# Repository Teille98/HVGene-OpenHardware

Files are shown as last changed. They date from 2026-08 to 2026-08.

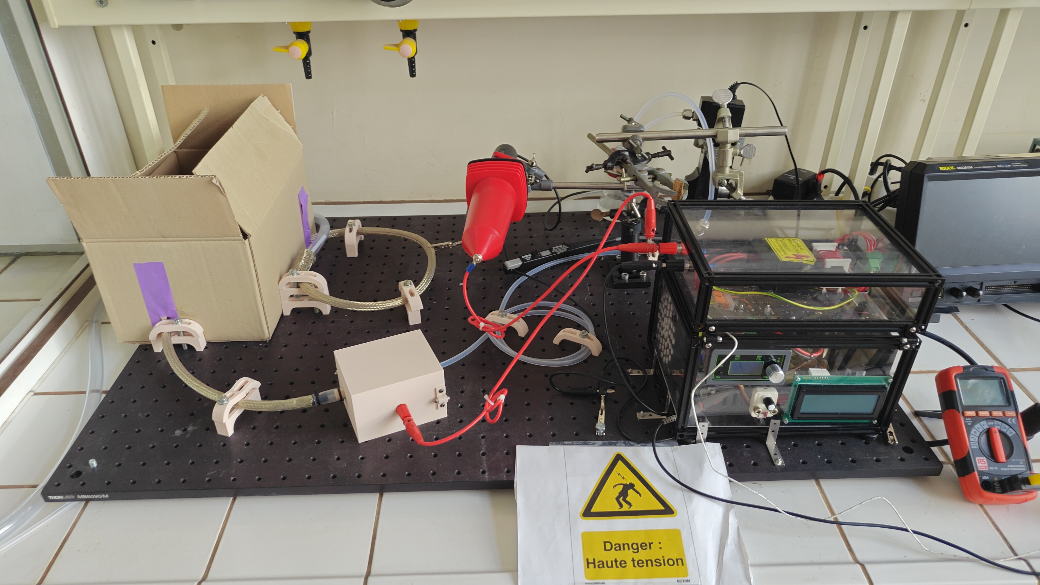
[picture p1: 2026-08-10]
docs/Figures/Setup_Photos/setup_1.jpg

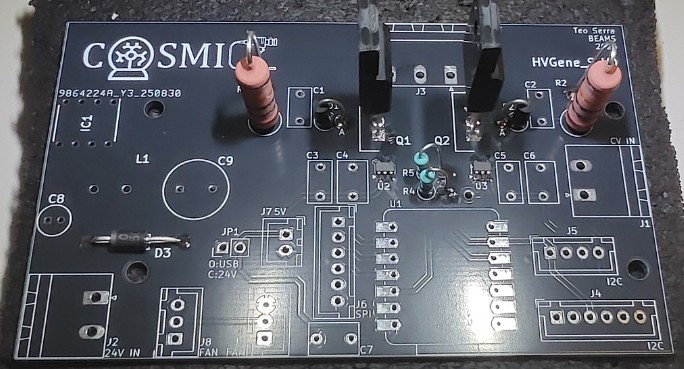
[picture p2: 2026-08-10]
docs/Figures/Build_Steps/PCB_step3&4.jpg

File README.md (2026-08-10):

# HVGene — Open-Source High-Voltage Power Supply for Cold Atmospheric Plasma

Open-source, digitally controlled high-voltage AC power supply for cold atmospheric
plasma (CAP) research, developed with a specific focus on flexible-endoscope
decontamination applications. The platform delivers either continuous sinusoidal
high-voltage excitation or pulsed AC trains, with explicit user control over input
voltage, operating frequency, duty cycle, timing, and operating mode.

This repository accompanies the following HardwareX article:

> *Open-Source High Voltage Power Supply for Cold Atmospheric Plasma Production*,
> HardwareX (2026). DOI: _to be added once assigned_.

If you use this hardware, firmware, or documentation, please cite the article above.

## Repository structure

This project mixes three kinds of content, each released under the license most
appropriate for that kind of content — see the `LICENSE` file inside each folder
for the exact terms.

```
HVGene_OpenHardware/
├── hardware/          Electronics and mechanical design files
│   ├── LICENSE        CERN-OHL-P-2.0 (permissive open hardware licence, unmodified)
│   ├── NOTICE          Copyright notice (kept separate — the licence text itself
│   │                   must not be modified, per its own Preamble)
│   ├── KiCAD/          PCB schematic and layout (push-pull inverter board)
│   ├── CAD-Fusion360/  3D mechanical design (enclosure, mounting)
│   ├── Cutting/        Laser-cutting SVG files (LV/HV plates)
│   └── BOM.xlsx        Bill of materials
├── firmware/           RP2040 / MicroPython control firmware
│   ├── LICENSE          MIT
│   ├── main.py, lib/    Firmware source
│   └── tests/           Bench validation scripts (I2C, PIO, timing)
├── docs/                Build photos, diagrams, and other documentation media
│   ├── LICENSE           CC BY-SA 4.0
│   └── Figures/          All figures used in the article, plus device/setup/plasma
│                         photos, CAD renders, build-step and scope-capture images
└── zip/                 Pre-packaged .zip archives of the folders above, matching
                          the Design Files table in the HardwareX article
```

## Versioning

The version tagged and archived alongside the HardwareX article submission is the
exact hardware/firmware state described and validated in that article. This
repository may continue to evolve after that point (bug fixes, improvements,
community contributions); the archived release is the one to use for reproducing
the results reported in the article.

## Safety

This hardware generates high voltages (up to several tens of kV) and involves
mains-connected power electronics. Building and operating it requires
appropriate electrical safety training. See the "Safety Concerns" and
"Operation instructions" sections of the article before use.

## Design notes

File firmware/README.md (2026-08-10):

# HVGene

## Quick Description

HVGene is an RP2040-based high-voltage signal generator (MicroPython) with an I2C LCD and rotary encoder user interface.

The firmware provides two modes:
- SQUARE: continuous square signal
- PULSE: ON/OFF gating of the square signal with adjustable pulse frequency and duty cycle

## Target Hardware

- RP2040 (Raspberry Pi Pico / XIAO RP2040)
- M5Stack U135 encoder (I2C 0x40)
- LCD 20x4 NHD-0420D3Z (I2C 0x28)

Used pins:
- GPIO0: MOSFET A gate (PIO SM0, push-pull)
- GPIO1: MOSFET B gate (PIO SM0, complementary — same SM as GPIO0)
- GPIO6: I2C SDA
- GPIO7: I2C SCL

> **Note**: there is no dedicated "pulse gate" pin. PULSE mode gating is
> achieved by overriding the GPIO pad OUTOVER registers (RP2040 CTRL),
> which forces both GPIO0/GPIO1 LOW without stopping the PIO SM.

## Quick Start

1. Flash MicroPython onto the RP2040.
2. Copy main.py and the lib/ folder to the board.
3. Connect the RP2040 to the custom PCB.
4. Reboot the board.

## Project Structure

```
HVGene_Simple/
|-- main.py
|-- README.md
|-- lib/
|   |-- config.py
|   |-- generator.py
|   |-- hardware.py
|   |-- logger.py
|   |-- pio_programs.py
|   |-- storage.py
|   `-- README.md
`-- tests/
    |-- README.md
    |-- test_i2c_devices.py
    |-- test_lcd_output.py
    |-- test_encoder.py
    |-- test_gpio_output.py
    |-- test_pio_simple.py
    |-- test_pulse_timing.py
    `-- test_duty_cycle.py
```

## Main File Roles

- `main.py`: firmware entry point.
- `lib/config.py`: configuration constants (GPIO, frequencies, UI limits).
- `lib/pio_programs.py`: PIO program for push-pull drive.
- `lib/hardware.py`: I2C drivers (encoder + LCD).
- `lib/generator.py`: application logic and UI state machine.
- `lib/logger.py`: logging.
- `lib/storage.py`: settings save/load.
- `tests/`: hardware and timing validation scripts.

## Tests

The recommended procedure and test descriptions are available in [tests/README.md](tests/README.md).

Recommended order:
1. `test_i2c_devices.py`
2. `test_lcd_output.py`
3. `test_encoder.py`
4. `test_gpio_output.py`
5. `test_pio_simple.py`
6. `test_pulse_timing.py`
7. `test_duty_cycle.py`

## License

MIT — see [LICENSE](LICENSE).

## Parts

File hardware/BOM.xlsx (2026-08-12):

Category | Designator | Part | Value | Component / Ref. | Qty | Unit cost | Total cost | Supplier | Source of materials | Notes
PCB | U1 | MicroC |  | Seeed Studio XIAO RP2040 | 1 | 5.24 € | 5.24 € | RS | https://befr.rs-online.com/web/p/arduino-compatible-boards-kits/2500966
PCB | U2, U3 | IC |  | MCP1416T-E/OT | 2 | 3.34 € | 6.68 € | Mouser | https://www.mouser.be/ProductDetail/Microchip-Technology/MCP1416T-E-OT?qs=hH%252BOa0VZEiBT%252BgAjATFU6A%3D%3D
PCB | IC1 | IC |  | LM2574-5.0YN | 1 | 1.04 € | 1.04 € | Mouser | https://www.mouser.be/ProductDetail/Microchip-Technology/LM2574-5.0YN?qs=kh6iOki%2FeLG8tRVzGWSPaw%3D%3D
PCB | Q1, Q2 | MOSFET |  | IRFI4321PBF | 2 | 1.50 € | 3.00 € | Mouser | https://www.mouser.be/ProductDetail/Infineon-Technologies/IRFI4321PBF?qs=9%252BKlkBgLFf1U%252BCGUGLBmvA%3D%3D
PCB | D1, D2 | Diode |  | UF4005 | 2 | 0.22 € | 0.45 € | Mouser | https://www.mouser.be/ProductDetail/Diotec-Semiconductor/UF4005?qs=OlC7AqGiEDkmzrSpAlXJ9Q%3D%3D
PCB | D3 | Diode |  | SB160-E3/54 | 1 | 0.20 € | 0.20 € | Mouser | https://www.mouser.be/ProductDetail/Vishay-General-Semiconductor/SB160-E3-54?qs=u91jd7aysvPQGAQKmVmbIA%3D%3D
PCB | R1, R2 | Resistor | 100 KOhm | FMP300FRF73-100K | 2 | 0.27 € | 0.53 € | Mouser | https://www.mouser.be/ProductDetail/YAGEO/FMP300FRF73-100K
PCB | R3, R4 | Resistor | 47 KOhm | LR1F47K | 2 | 0.09 € | 0.17 € | Mouser | https://www.mouser.be/ProductDetail/TE-Connectivity-Holsworthy/LR1F47K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
PCB | C1, C2 | Capacitor | 0,01 uF | RDER73A103K2K1H03B | 2 | 0.65 € | 1.31 € | Mouser | https://www.mouser.be/ProductDetail/Murata-Electronics/RDER73A103K2K1H03B
PCB | C3, C5 | Capacitor | 0,1 uF | K104K15X7RF5WH5 | 2 | 0.22 € | 0.45 € | Mouser | https://www.mouser.be/ProductDetail/Vishay-BC-Components/K104K15X7RF5WH5?qs=8fb2TFeI5qGYDjl7%252BWZxcg%3D%3D
PCB | C4, C6 | Capacitor | 1 uF | FG28X7R1E105KRT00 | 2 | 0.27 € | 0.53 € | Mouser | https://www.mouser.be/ProductDetail/TDK/FG28X7R1E105KRT00?qs=vNwBHymccZ9WlwKQSeNEkg%3D%3D
PCB | C7 | Capacitor | 10 uF | FK24X5R1A106K | 1 | 0.35 € | 0.35 € | Mouser | https://www.mouser.be/ProductDetail/TDK/FK24X5R1A106K?qs=zLBlM7QTTNplmyxmjYlQjw%3D%3D
PCB | C8 | Capacitor | 22 uF | 860020672011 | 1 | 0.10 € | 0.10 € | Mouser | https://www.mouser.be/ProductDetail/Wurth-Elektronik/860020672011?qs=0KOYDY2FL2%2FKkbEhyek4UA%3D%3D
PCB | C9 | Capacitor | 220 uF | ESH227M050AH1AA | 1 | 0.48 € | 0.48 € | Mouser | https://www.mouser.be/ProductDetail/KEMET/ESH227M050AH1AA?qs=w9hhVRgtvfmnb2YOvt619g%3D%3D
PCB | L1 | Inductor | 330 uH | 7447471331 | 1 | 2.24 € | 2.24 € | Mouser | https://www.mouser.be/ProductDetail/Wurth-Elektronik/7447471331?qs=VxkwJfKV0FSJeL%252B3Zn%2FUiQ%3D%3D
PCB | JP1 | Jumper |  | 60900213421 | 1 | 0.27 € | 0.27 € | Mouser | https://www.mouser.be/ProductDetail/Wurth-Elektronik/60900213421?qs=W%252B2sBeLta1bsO5t19%2FBN7Q%3D%3D
PCB | J1, J2 | Connector |  | RS PRO, 2 Way, 1 Row, Right Angle PCB Terminal Block Header | 2 | 2.81 € | 5.62 € | RS | https://befr.rs-online.com/web/p/pluggable-terminal-blocks/8971262
PCB | J3 | Connector |  | RS 5.08mm Horizontal PCB Terminal Block Headers | 1 | 2.84 € | 2.84 € | RS | https://befr.rs-online.com/web/p/pcb-headers/8971266
PCB | J4, J6 | Connector |  | JST XH Straight, 6 pin 1 Row, 2.5 mm, male | 2 | 0.26 € | 0.52 € | RS | https://befr.rs-online.com/web/p/pcb-headers/7495228
PCB | J5 | Connector |  | JST XH Straight, 4 pin 1 Row, 2.5 mm, male | 1 | 0.19 € | 0.19 € | RS | https://befr.rs-online.com/web/p/pcb-headers/1755445
PCB | J7 | Connector |  | JST XH Straight, 2 pin 1 Row, 2.5 mm, male | 1 | 0.21 € | 0.21 € | RS | https://befr.rs-online.com/web/p/pcb-headers/1755499
PCB | J8, J9 | Connector |  | JST XH Straight, 3 pin 1 Row, 2.5 mm, male | 2 | 0.20 € | 0.40 € | RS | https://befr.rs-online.com/web/p/pcb-headers/1755529
Electrical | PCB | Alternator |  | custom PCB (JLCPCB manufactured) | 1 | 2.10 € | 2.10 € | JLCPCB | https://jlcpcb.com/
Electrical | LCD_SCREEN | UI_Screen |  | NHD-0420D3Z-FL-GBW-V3 | 1 | 14.73 € | 14.73 € | Mouser | https://www.mouser.be/ProductDetail/Newhaven-Display/NHD-0420D3Z-FL-GBW-V3?qs=qFF%252BBcFBHba4i0K1fcOqkw%3D%3D
Electrical | BUCK_MODULE | Voltage Regulator |  | LM2596 buck converter module (dual board w/ LCD driver) | 1 | 23.62 € | 23.62 € | EC-buying - Amazon | https://www.amazon.com/dp/B0B38GYF74?ref_=ppx_printOD_title_dt_b_fed_asin_title_0_0
Electrical | LCD_BUCK_MODULE | UI_Screen |  |  |  |  |  |  |  | Bundled with BUCK_MODULE purchase (single module, two boards)
Electrical | FAN_80mm | Fan |  | CFM-8025V-232-330 | 2 | 5.43 € | 10.86 € | Mouser | https://www.mouser.be/ProductDetail/Same-Sky/CFM-8025V-232-330
Electrical | TXH_240-124 | DC Power Supply |  | TXH 240-124 | 1 | 116.59 € | 116.59 € | Mouser | https://www.mouser.be/ProductDetail/TRACO-Power/TXH-240-124?qs=ckJk83FOD0UI9bpkOG0QEg%3D%3D
Electrical | TRANSFO | Transformer |  | HF 15kV AC transformer | 1 | 24.99 € | 24.99 € | Highvoltageshop | https://highvoltageshop.com/epages/b73088c0-9f9a-4230-9ffc-4fd5c619abc4.sf/de_DE/
Electrical | ROT_ENCODER | UI_Command |  | M5Stack U135 | 1 | 6.84 € | 6.84 € | Mouser | https://www.mouser.be/ProductDetail/M5Stack/U135?qs=Li%252BoUPsLEnstnDfPQNf5Rw%3D%3D
Electrical | ROT_ENCODER_CBL | Cable |  |  |  |  |  |  |  | Cable supplied with ROT_ENCODER; no separate purchase
Electrical | CON_POWER | Connector |  | IEC power connector | 1 | 12.29 € | 12.29 € | RS | https://befr.rs-online.com/web/p/iec-connectors/8703271
Electrical | FUSE_HOLDER | Fuse Holder |  | fuse holder | 1 | 5.80 € | 5.80 € | RS | https://befr.rs-online.com/web/p/fuse-holders/5006211?gb=s | Grouped with CON_POWER in CAD sub-assembly; purchased separately
Electrical | FUSE | Fuse |  | cartridge fuse | 2 | 0.36 € | 0.71 € | RS | https://befr.rs-online.com/web/p/cartridge-fuses/6686007 | Grouped with CON_POWER in CAD sub-assembly; purchased separately
Electrical | BAN_CON_BLK | Connector |  | binding post, black | 1 | 3.89 € | 3.89 € | RS | https://befr.rs-online.com/web/p/binding-posts/0738345
Electrical | BAN_CON_RED | Connector |  | binding post, red | 1 | 3.85 € | 3.85 € | RS | https://befr.rs-online.com/web/p/binding-posts/0738351
Electrical | JST_6PIN_MALE | Connector |  | JST XH Straight, 6 pin 1 Row, 2.5 mm, male | 1 | 0.26 € | 0.26 € | RS | https://befr.rs-online.com/web/p/pcb-headers/7495228
Electrical | JST_6PIN_FEM | Connector |  | JST XH Straight, 6 pin 1 Row, 2.5 mm, female | 2 | 0.14 € | 0.28 € | RS | https://befr.rs-online.com/web/p/wire-housings-plugs/8201620
Electrical | JST_4PIN_FEM | Connector |  | JST XH Straight, 4 pin 1 Row, 2.5 mm, female | 1 | 0.11 € | 0.11 € | RS | https://befr.rs-online.com/web/p/wire-housings-plugs/8201618
Electrical | JST_3PIN_FEM | Connector |  | JST XH Straight, 3 pin 1 Row, 2.5 mm, female | 2 | 0.11 € | 0.22 € | RS | https://befr.rs-online.com/web/p/wire-housings-plugs/8201614
Electrical | WAGO_5W | Connector | / | WAGO 221-415, 5-way lever connector, 0.2-4mm2 (24-12 AWG), 32A | 1 | 1.08 € | 1.08 € | RS | https://befr.rs-online.com/web/p/splice-connectors/8837557/
Electrical | CRIMP_JST | Crimp |  | crimp contact for JST XH | 16 | 0.03 € | 0.48 € | RS | https://befr.rs-online.com/web/p/crimp-contacts/1235947
Electrical | CRIMP_SPADE | Crimp |  | spade connector | 3 | 0.06 € | 0.18 € | RS | https://benl.rs-online.com/web/p/spade-connectors/1788311
Electrical | CRIMP_RING | Crimp |  | ring terminal | 3 | 0.06 € | 0.17 € | RS | https://benl.rs-online.com/web/p/ring-terminals/6139508
Electrical | TERM_BLOCK_3POS_M | Connector |  | pluggable terminal block, 3 pos, male | 1 | 1.98 € | 1.98 € | RS | https://befr.rs-online.com/web/p/pluggable-terminal-blocks/1468337
Electrical | TERM_BLOCK_2POS_F | Connector |  | pluggable terminal block, 2 pos, female | 2 | 0.75 € | 1.49 € | RS | https://befr.rs-online.com/web/p/pluggable-terminal-blocks/8971219
Electrical | TERM_BLOCK_3POS_F | Connector |  | pluggable terminal block, 3 pos, female | 1 | 1.42 € | 1.42 € | RS | https://befr.rs-online.com/web/p/pluggable-terminal-blocks/7900705
Mechanical | MakerBeam_CUBE_CORNER_10x10x10mm | Bracket |  | corner cube, 12p | 16 | 1.58 € | 25.31 € | MakerBeam | https://www.makerbeam.com/makerbeam-corner-cubes-12p-black-for-makerbeam.html
Mechanical | BOLT_CSK_M3_4mm | Bolt |  |  | 52 |  |  |  |  | Bundled with MakerBeam Corner Cubes kit + T-slot nuts kit; no separate purchase
Mechanical | MakerBeam_HINGE_AXE | Hinge |  | hinge, 8p/4p kit | 4 | 5.00 € | 20.00 € | MakerBeam | https://www.makerbeam.com/makerbeam-hinges-for-makerbeam-8p-4p.html
Mechanical | MakerBeam_HINGE_LOCKNUT | Hinge |  |  |  |  |  |  |  | Bundled with MakerBeam_HINGE_AXE purchase (single hinge kit: 8 pieces + 4 axes + 4 locknuts)
Mechanical | MakerBeam_HINGE_PIECE | Hinge |  |  |  |  |  |  |  | Bundled with MakerBeam_HINGE_AXE purchase (single hinge kit: 8 pieces + 4 axes + 4 locknuts)
Mechanical | MakerBeam_PROFILE_10x10x40mm | Profile |  | 40mm profile, 8p | 4 | 0.59 € | 2.38 € | MakerBeam | https://www.makerbeam.com/makerbeam-40mm-8p-black-makerbeam.html
Mechanical | MakerBeam_PROFILE_10x10x100mm | Profile |  | 100mm profile, 16p | 4 | 1.12 € | 4.50 € | MakerBeam | https://www.makerbeam.com/makerbeam-100mm-16p-black-makerbeam.html
Mechanical | MakerBeam_PROFILE_10x10x150mm | Profile |  | 150mm profile, 6p | 8 | 1.69 € | 13.53 € | MakerBeam | https://www.makerbeam.com/makerbeam-150mm-6p-black-makerbeam.html
Mechanical | MakerBeam_PROFILE_10x10x200mm | Profile |  | 200mm profile, 8p | 8 | 1.99 € | 15.90 € | MakerBeam | https://www.makerbeam.com/makerbeam-200mm-8p-black-makerbeam.html
Mechanical | MakerBeam_TNUT_10x10mm | Nut |  | T-slot nut, 25p | 8 | 0.64 € | 5.11 € | MakerBeam | https://www.makerbeam.com/makerbeam-t-slot-nuts-for-makerbeam-25p.html
Mechanical | NUT_M1.6 | Nut |  | hex nut M1.6 | 2 | 0.24 € | 0.48 € | RS | https://befr.rs-online.com/web/p/hex-nuts/1795726
Mechanical | NUT_M3 | Nut |  | nut, regular, 250p | 12 | 0.03 € | 0.31 € | MakerBeam | https://www.makerbeam.com/makerbeam-nuts-regular-250p.html
Mechanical | NUT_M4 | Nut |  | hex nut M4 | 8 | 0.05 € | 0.42 € | RS | https://befr.rs-online.com/web/p/hex-nuts/0527252
Mechanical | NUT_M5 | Nut |  | hex nut M5 | 2 | 0.03 € | 0.06 € | RS | https://benl.rs-online.com/web/p/hex-nuts/2874065
Mechanical | BOLT_CSK_M3_8mm | Bolt |  | socket screw M3x8 | 2 | 0.20 € | 0.40 € | RS | https://befr.rs-online.com/web/p/socket-screws/3044918
Mechanical | BOLT_BHSCS_M3_4mm | Bolt |  |  |  |  |  | MakerBeam |  | Bundled with MakerBeam T-slot nuts kit (TNUT_10x10mm); no separate purchase
Mechanical | BOLT_SHCS_M3_16mm | Bolt |  | socket screw M3x16 | 2 | 0.57 € | 1.14 € | RS | https://befr.rs-online.com/web/p/socket-screws/1871235
Mechanical | BOLT_SHCS_M1.6_12mm | Bolt |  | socket screw M1.6x12 | 4 | 1.11 € | 4.43 € | RS | https://befr.rs-online.com/web/p/socket-screws/0281007
Mechanical | BOLT_SHCS_M4_12mm | Bolt |  | socket screw M4x12 | 8 | 0.13 € | 1.03 € | RS | https://befr.rs-online.com/web/p/socket-screws/4679880
Mechanical | BOLT_BHSCS_M5_16mm | Bolt |  | socket screw M5x16 | 2 | 0.26 € | 0.53 € | RS | https://befr.rs-online.com/web/p/socket-screws/1838698
Mechanical | HEATSINK | MOSFET heatsink |  | heatsink | 2 | 3.50 € | 6.99 € | RS | https://befr.rs-online.com/web/p/heatsinks/7124295
Mechanical | THERMAL_PASTE | MOSFET thermal paste |  | thermal grease | 1 | 21.92 € | 21.92 € | RS | https://befr.rs-online.com/web/p/thermal-grease/1938248
Mechanical | STANDOFF_M3_5mm | Standoff |  | standoff M3x5 | 8 | 0.21 € | 1.67 € | RS | https://befr.rs-online.com/web/p/standoffs/8066607
Mechanical | PLATE_HV_BACK | Plate |  | PMMA sheet 100x50cm x3mm | 1 | 38.80 € | 38.80 € | Brico | https://www.brico.be/fr/menuiserie/planches-plastique-verre-synthetique/verres-synthetiques/scala-plastics-plaque-de-plexi-acrylique-pmma-cristal-100x50cm-x-3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 | PMMA sheet - covers all plates below (11 plates cut from same sheet)
Mechanical | PLATE_HV_BOTTOM | Plate |  |  | 1 |  |  |  |  | Cut from the same PMMA sheet as PLATE_HV_BACK
Mechanical | PLATE_HV_FRONT | Plate |  |  | 1 |  |  |  |  | Cut from the same PMMA sheet as PLATE_HV_BACK
Mechanical | PLATE_HV_SIDE | Plate |  |  | 2 |  |  |  |  | Cut from the same PMMA sheet as PLATE_HV_BACK
Mechanical | PLATE_HV_TOP | Plate |  |  | 1 |  |  |  |  | Cut from the same PMMA sheet as PLATE_HV_BACK
Mechanical | PLATE_LV_BACK | Plate |  |  | 1 |  |  |  |  | Cut from the same PMMA sheet as PLATE_HV_BACK
Mechanical | PLATE_LV_BOTTOM | Plate |  |  | 1 |  |  |  |  | Cut from the same PMMA sheet as PLATE_HV_BACK
Mechanical | PLATE_LV_FRONT | Plate |  |  | 1 |  |  |  |  | Cut from the same PMMA sheet as PLATE_HV_BACK
Mechanical | PLATE_LV_SIDE | Plate |  |  | 1 |  |  |  |  | Cut from the same PMMA sheet as PLATE_HV_BACK
Mechanical | PLATE_LV_SIDE_CON | Plate |  |  | 1 |  |  |  |  | Cut from the same PMMA sheet as PLATE_HV_BACK
Mechanical | PLATE_LV_TOP | Plate |  |  | 1 |  |  |  |  | Cut from the same PMMA sheet as PLATE_HV_BACK
 |  |  |  |  |  | TOTAL COST: | 431.67 €

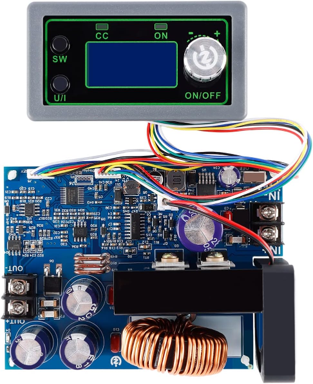
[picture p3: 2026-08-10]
docs/Figures/Component_Photos/BUCK_MODULE & LCD_BUCK_MODULE.png

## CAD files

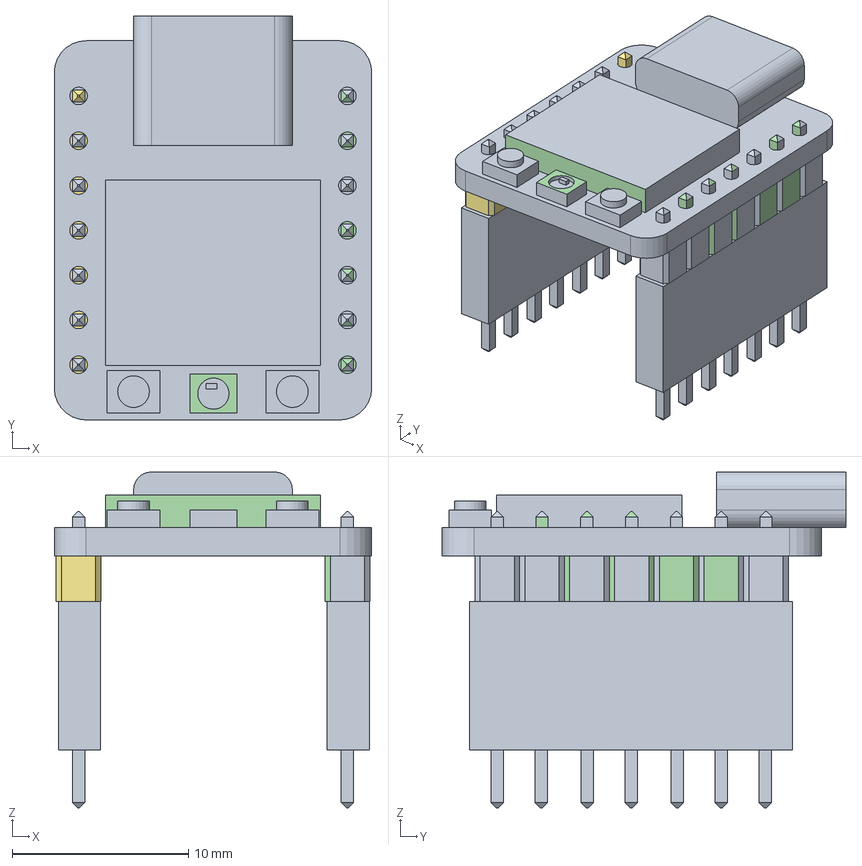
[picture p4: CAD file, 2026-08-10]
hardware/KiCAD/Seeeduino-XIAO-KICAD/xiao_rp2040-main/xiao_rp2040-main/XIAOSocketAssembly.FCStd
18.0 x 22.9 x 19.0 mm
PCB_001
USBC2_001
PinHeaderRowAssembly_001
PinHeaderRowAssembly_002
Switch_001
Switch_002
Socket_001
Socket_002
Sockets
Switches
PinHeaders
LED_ESP32
USB_LED_ESP32
PCB_Components
Connectors
AllComponents
FullAssembly

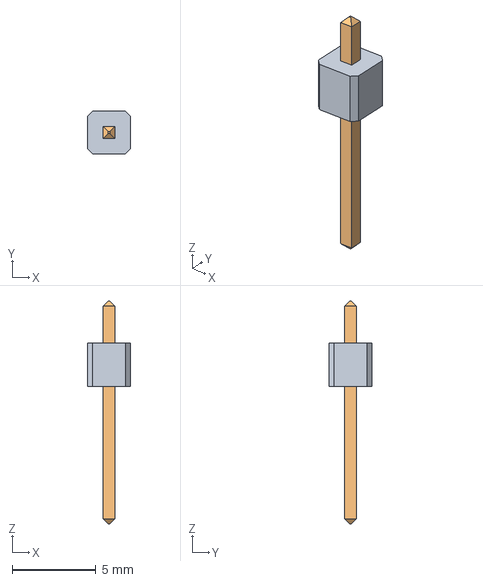
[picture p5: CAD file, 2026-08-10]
hardware/KiCAD/Seeeduino-XIAO-KICAD/xiao_rp2040-main/xiao_rp2040-main/OnePinHeaderAssembly.FCStd
2.54 x 2.54 x 13.3 mm
PinHeader_001
Pin_001

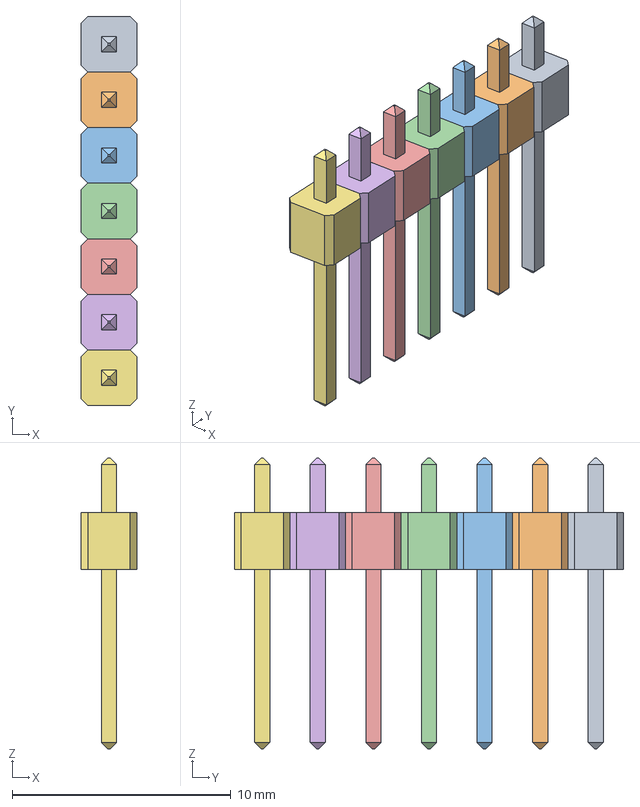
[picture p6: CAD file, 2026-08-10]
hardware/KiCAD/Seeeduino-XIAO-KICAD/xiao_rp2040-main/xiao_rp2040-main/PinHeaderRowAssembly.FCStd
2.54 x 17.8 x 13.3 mm
OnePinHeaderAssembly_001
OnePinHeaderAssembly_002
OnePinHeaderAssembly_003
OnePinHeaderAssembly_004
OnePinHeaderAssembly_005
OnePinHeaderAssembly_006
OnePinHeaderAssembly_007

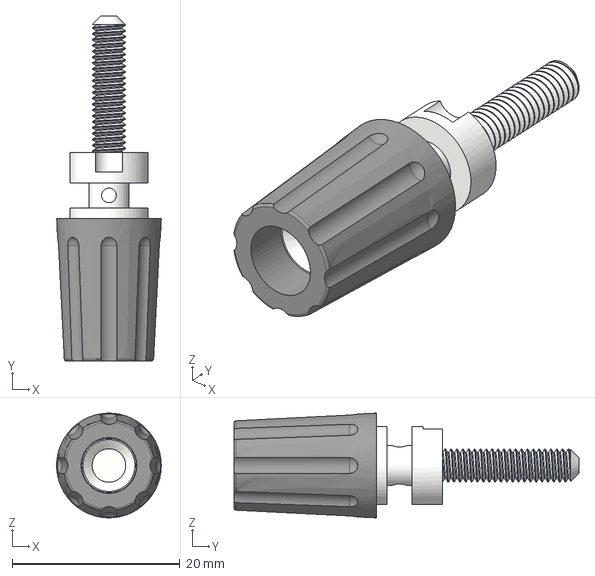
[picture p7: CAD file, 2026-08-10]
hardware/CAD-Fusion360/ELEC_comp/BAN_CON_BLK.step
12.5 x 41.2 x 12.5 mm

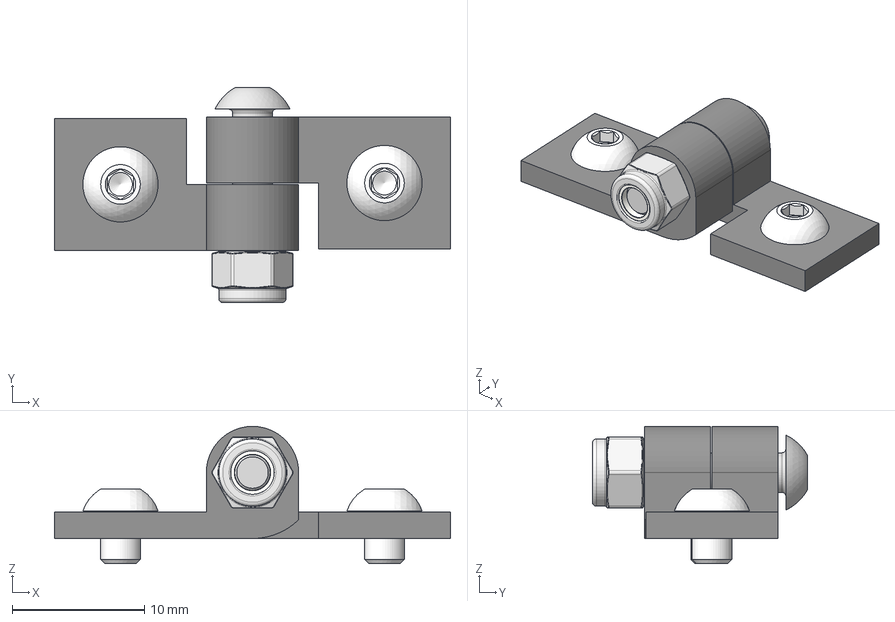
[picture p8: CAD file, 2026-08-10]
hardware/CAD-Fusion360/SUB_ASSEMBLY/SA_MakerBeam_HINGE.step
30.0 x 16.3 x 10.4 mm
M3 Nyloc Nut

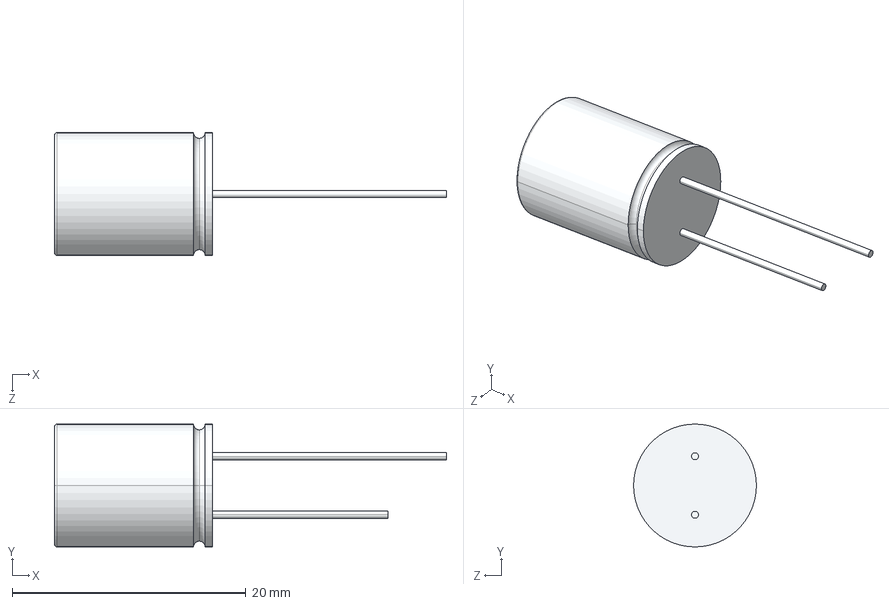
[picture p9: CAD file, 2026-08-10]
hardware/KiCAD/LIB_ESH227M050AH1AA/ESH227M050AH1AA/3D/ESH227M050AH1AA.stp
33.5 x 10.5 x 10.5 mm

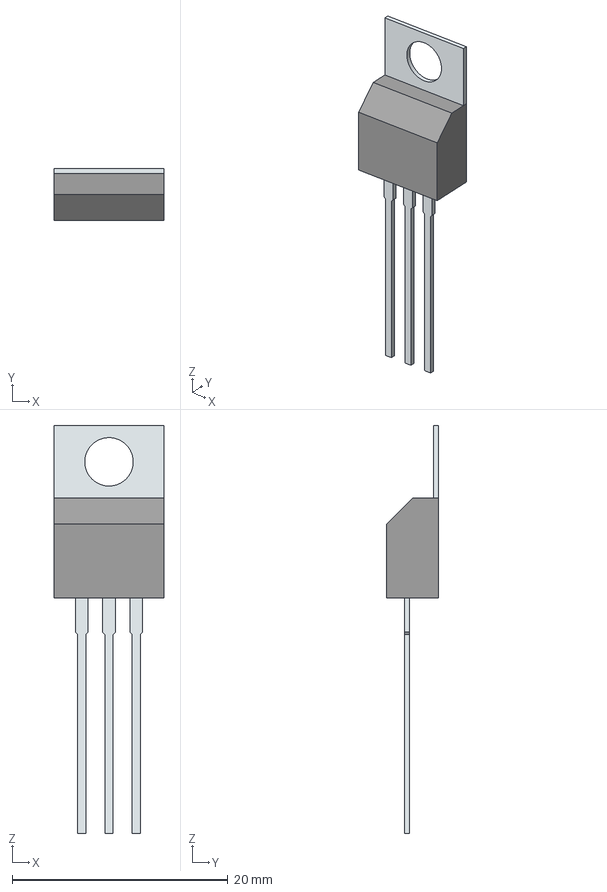
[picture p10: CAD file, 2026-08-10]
hardware/KiCAD/LIB_IRFI4321PBF/IRFI4321PBF/3D/IRFI4321PBF.stp
10.2 x 4.83 x 37.8 mm
Tab
PinsArray

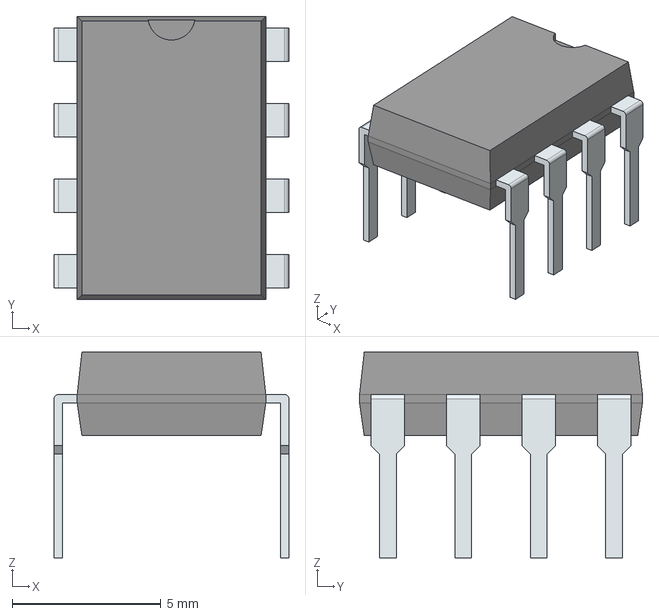
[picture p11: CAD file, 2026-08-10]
hardware/KiCAD/LIB_LM2574-5.0YN/LM2574-5.0YN/3D/LM2574-5.0YN.stp
7.91 x 9.53 x 6.93 mm
PinsArrayLR

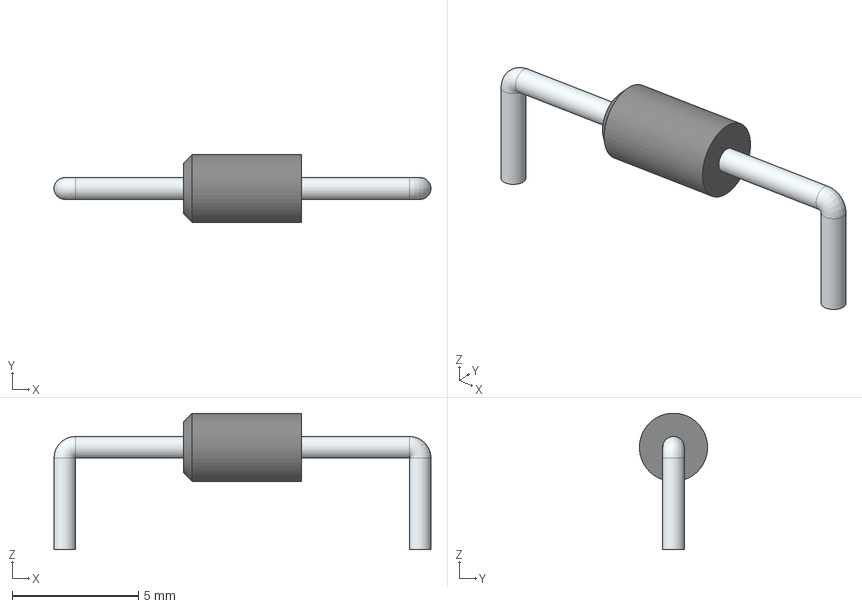
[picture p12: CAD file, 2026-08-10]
hardware/KiCAD/LIB_SB160-E3_54/SB160-E3_54/3D/SB160-E3_54.stp
14.9 x 2.70 x 5.40 mm

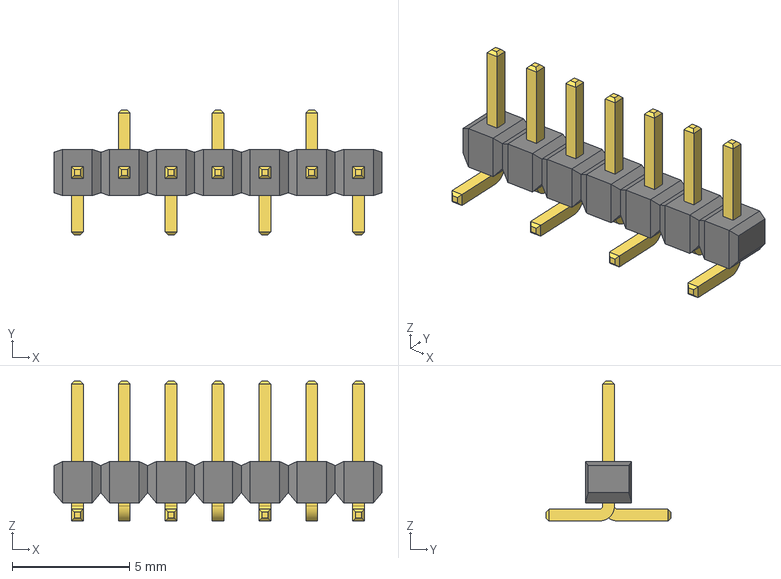
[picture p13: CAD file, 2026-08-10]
hardware/KiCAD/Seeeduino-XIAO-KICAD/TMM-107-01-G-S-SM_SAI.step
14.0 x 5.33 x 5.97 mm

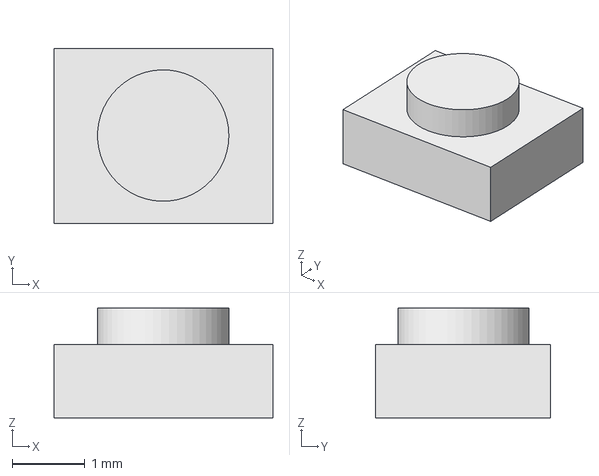
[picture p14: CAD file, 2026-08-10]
hardware/KiCAD/Seeeduino-XIAO-KICAD/xiao_rp2040-main/xiao_rp2040-main/Switch.FCStd
3.00 x 2.40 x 1.50 mm

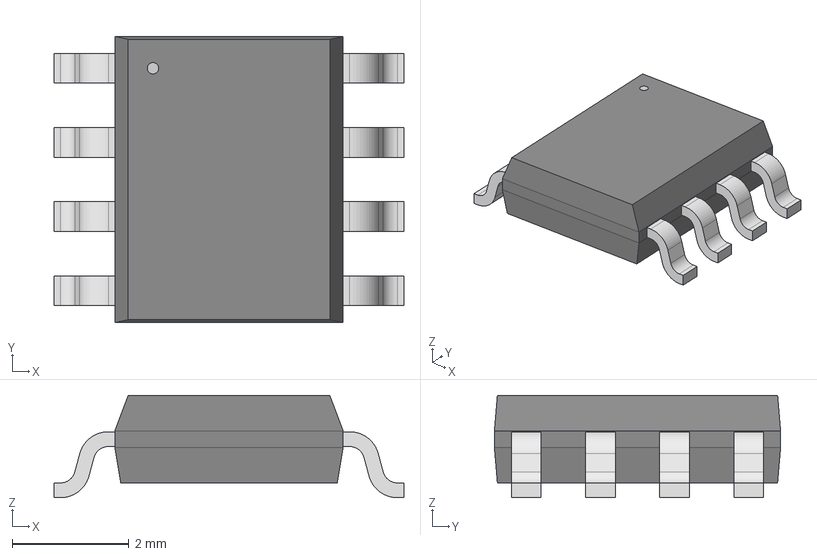
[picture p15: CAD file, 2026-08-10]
hardware/KiCAD/ul_MCP41010-E-SN/SOIC8-N_MC_MCH.step
5.99 x 4.90 x 1.75 mm

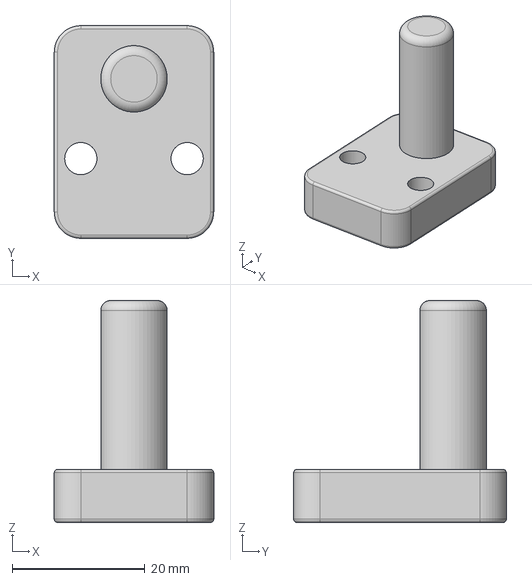
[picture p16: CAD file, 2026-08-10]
hardware/CAD-Fusion360/ELEC_comp/ROT_ENCODER.step
24.0 x 32.0 x 33.4 mm

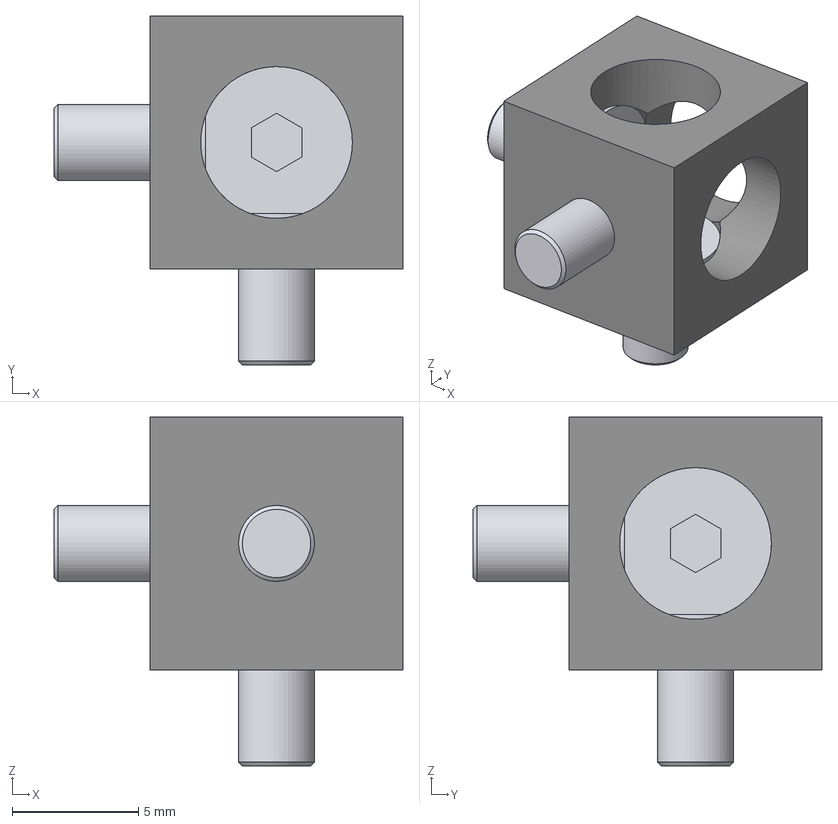
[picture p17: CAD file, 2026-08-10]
hardware/CAD-Fusion360/SUB_ASSEMBLY/SA_MakerBeam_CORNER.step
13.8 x 13.8 x 13.8 mm
101619-2 m3x4 x 3

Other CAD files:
hardware/KiCAD/Seeeduino-XIAO-KICAD/xiao_rp2040-main/xiao_rp2040-main/PinHeaderAssembly.FCStd
hardware/KiCAD/Seeeduino-XIAO-KICAD/ssw-107-01-t-s.stp
hardware/CAD-Fusion360/ELEC_comp/TRANSFO.step
hardware/CAD-Fusion360/MECHA_comp/PLATE_HV_SIDE.step
hardware/CAD-Fusion360/ELEC_comp/BAN_CON_BLK.f3d
hardware/CAD-Fusion360/ELEC_comp/BAN_CON_RED.f3d
hardware/CAD-Fusion360/ELEC_comp/BAN_CON_RED.step
hardware/CAD-Fusion360/ELEC_comp/BUCK_MODULE.f3d
hardware/CAD-Fusion360/ELEC_comp/BUCK_MODULE.step
hardware/CAD-Fusion360/ELEC_comp/CON_POWER.f3d
hardware/CAD-Fusion360/ELEC_comp/FAN_80mm.f3d
hardware/CAD-Fusion360/ELEC_comp/FAN_80mm.step
hardware/CAD-Fusion360/ELEC_comp/LCD_BUCK_MODULE.f3d
hardware/CAD-Fusion360/ELEC_comp/LCD_BUCK_MODULE.step
hardware/CAD-Fusion360/ELEC_comp/LCD_SCREEN.f3d
hardware/CAD-Fusion360/ELEC_comp/LCD_SCREEN.step
hardware/CAD-Fusion360/ELEC_comp/ROT_ENCODER.f3d
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

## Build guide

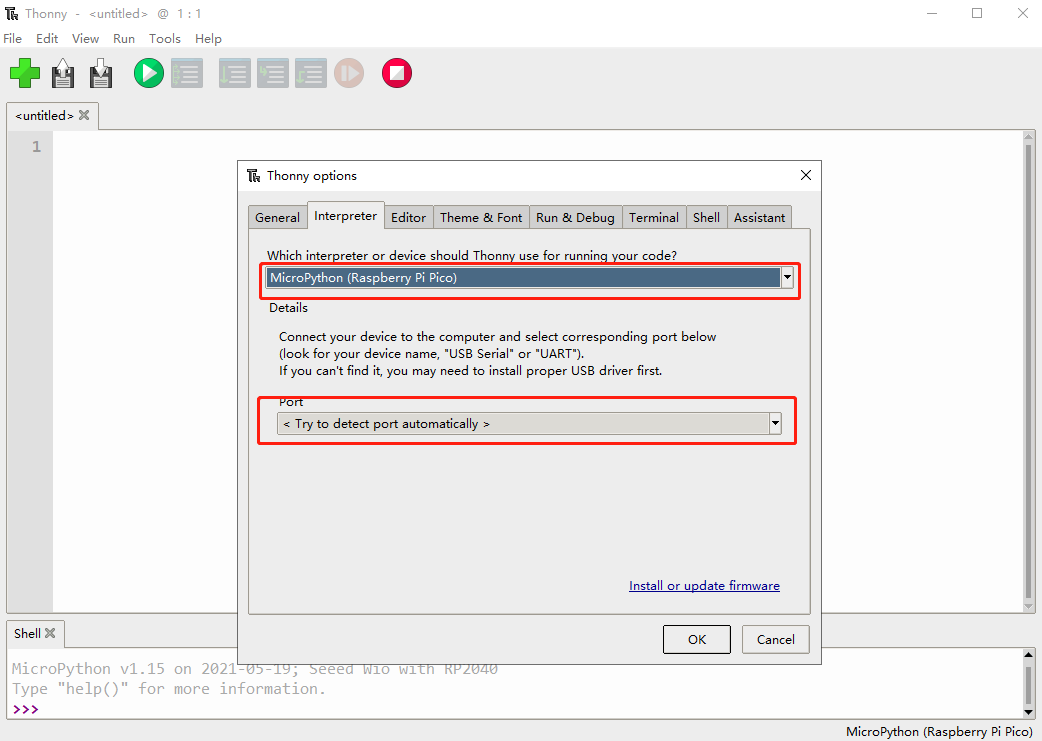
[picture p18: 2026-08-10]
docs/Figures/Article_Figures/Fig13_Thonny_Interpreter_Setup.png

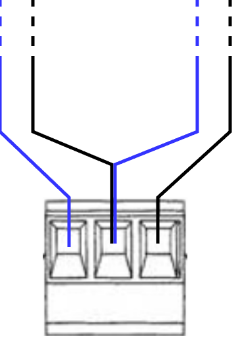
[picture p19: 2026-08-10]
docs/Figures/Article_Figures/Screw_Terminal_Wiring_Detail.png

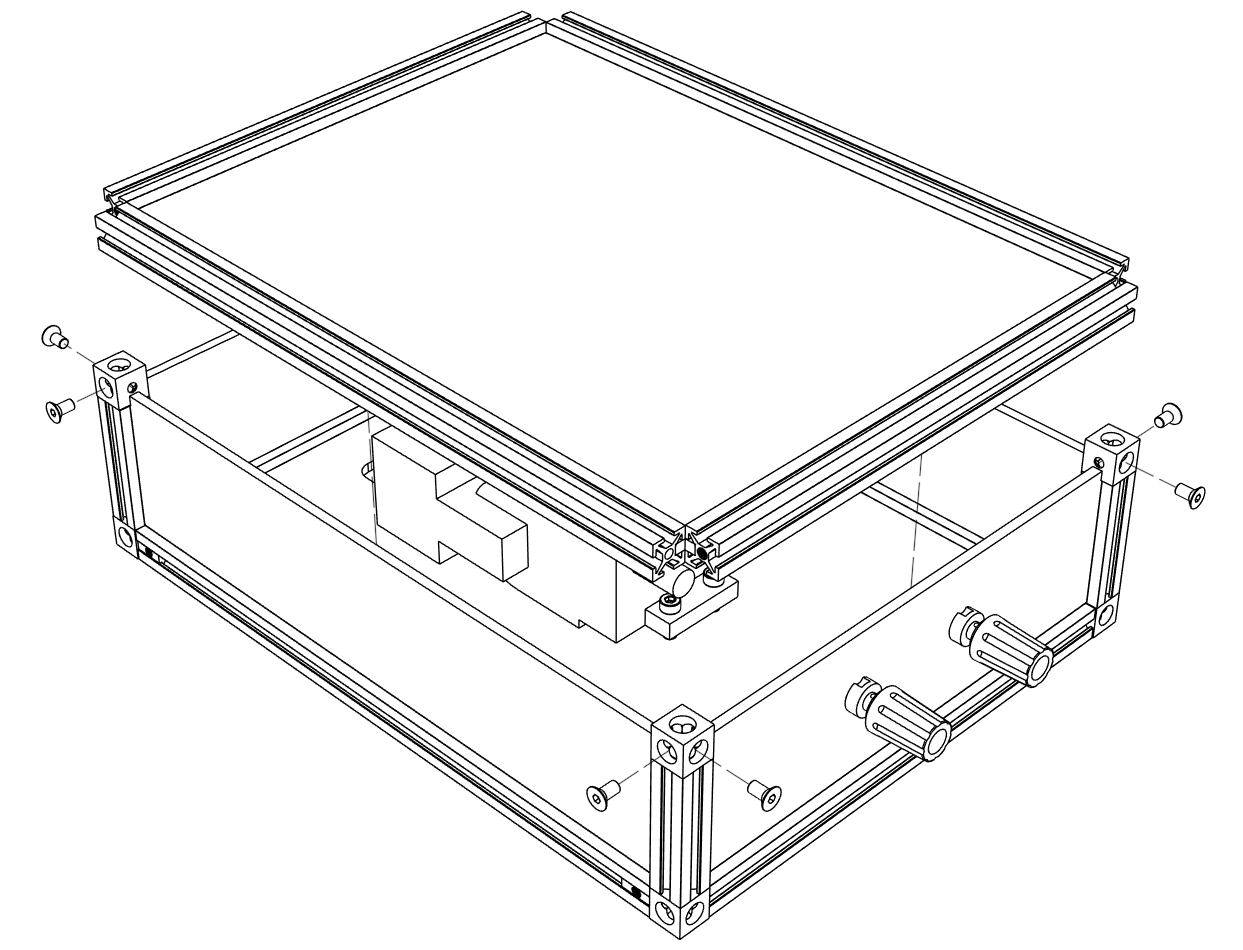
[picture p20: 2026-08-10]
docs/Figures/CAD_Renders/HV_assemb_step_3.png

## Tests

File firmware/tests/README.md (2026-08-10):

# Tests - Simple HV Generator

## Overview

This folder contains hardware-oriented test and diagnostic scripts for the RP2040-based HV generator.
All scripts are intended for manual validation through REPL logs and oscilloscope checks.

## Test Scripts

### test_i2c_devices.py

Fast hardware presence check for both I2C devices.

What it checks:
- I2C bus scan
- Encoder register probe (position + button)
- LCD clear command probe

Usage:

```python
import test_i2c_devices
test_i2c_devices.main()
```

### test_lcd_output.py

Visual LCD output test (line mapping and dynamic updates).

What it checks:
- LCD detection at 0x28
- Clear / contrast / backlight commands
- Text placement on 4 lines
- Timed progress update

Usage:

```python
import test_lcd_output
test_lcd_output.main()
```

### test_encoder.py

I2C validation for the M5Stack U135 rotary encoder unit.

What it checks:
- I2C bus scan
- Encoder position readout
- Push-button readout with basic debounce
- RGB LED write command sequence

Usage:

```python
import test_encoder
test_encoder.main()
```

### test_gpio_output.py

Quick GPIO0 sanity check, then a simple PIO square-wave output run.

Usage:

```python
import test_gpio_output
test_gpio_output.main()
```

### test_pio_simple.py

Minimal standalone PIO square-wave test on GPIO0.
Useful to isolate PIO behavior from the full application.

Usage:

```python
import test_pio_simple
```

### test_pulse_timing.py

PULSE mode timing verification using dedicated PIO state machines.
Prints theoretical ON/OFF timings for oscilloscope comparison.

Usage:

```python
import test_pulse_timing
```

### test_duty_cycle.py

Duty-cycle reference helper for menu-based PULSE mode control.
Prints expected ON/OFF durations and cycle counts for common settings.

Usage:

```python
import test_duty_cycle
test_duty_cycle.main()
```

## Recommended Test Procedure

Follow this sequence to reduce troubleshooting time.

### 1. Prepare Hardware

1. Power the RP2040 board.
2. Connect I2C peripherals:
   - SDA: GPIO6
   - SCL: GPIO7
3. Connect measurement tools:
   - Oscilloscope CH1 to GPIO0 (square output)
   - Oscilloscope CH2 to GPIO2 (gate signal)

### 2. Check I2C Presence

Run:

```python
import test_i2c_devices
test_i2c_devices.main()
```

Expected addresses:
- 0x40 (M5Stack U135 encoder)
- 0x28 (LCD controller)

### 3. Validate LCD Output

Run:

```python
import test_lcd_output
test_lcd_output.main()
```

Success criteria:
- All four lines are readable
- Progress line updates from 1/5 to 5/5

### 4. Validate Encoder and Button

Run:

```python
import test_encoder
test_encoder.main()
```

Success criteria:
- Encoder values change while rotating
- Button press and release events appear

### 5. Validate Basic GPIO/PIO Output

Run:

```python
import test_gpio_output
test_gpio_output.main()
```

Success criteria:
- Manual GPIO toggle phase completes
- PIO output phase runs for 10 seconds
- Scope shows a stable square wave on GPIO0

### 6. Validate PIO Frequency Steps

Run:

```python
import test_pio_simple
```

Success criteria:
- Low-frequency test visible on scope
- 1 kHz test visible and stable
- 30 kHz test active until interrupted

### 7. Validate PULSE Timing

Run:

```python
import test_pulse_timing
```

Success criteria:
- GPIO2 period is close to 100 ms at 10 Hz
- ON/OFF windows match printed cycle computations
- No visible jitter over multiple minutes

### 8. Validate Duty-Cycle Behavior Through UI

Run:

```python
import test_duty_cycle
test_duty_cycle.main()
```

Then in the main app menu:
1. Open menu with short press.
2. Select Duty %.
3. Adjust by encoder steps.
4. Confirm and measure GPIO2 ON/OFF ratio on scope.

## Expected Register Map (Encoder 0x40)

- 0x10: encoder position (signed 16-bit, little-endian)
- 0x20: button state
- 0x30: RGB LED control (4 bytes: led_index, R, G, B)

## Quick Troubleshooting

### No I2C devices found

- Check SDA/SCL wiring and ground reference
- Verify module power rails
- Lower I2C frequency and retry

### LCD writes fail

- Confirm LCD address is 0x28 in scan output
- Reboot the board and retry test_lcd_output.py
- Keep I2C frequency at 50 kHz

### Encoder does not respond

- Confirm device address is 0x40
- Reboot the board and rerun test_encoder.py

### No output on GPIO0

- Confirm probe ground and channel scaling
- Ensure no other code owns the same state machine or pin
- Retry with test_pio_simple.py low-frequency stage first

## References

- https://docs.m5stack.com/en/unit/encoder
- https://www.mouser.fr/datasheet/2/291/NHD_0420D3Z_FL_GBW_V3-1104093.pdf
- https://github.com/raspberrypi/pico-examples/tree/master/pio

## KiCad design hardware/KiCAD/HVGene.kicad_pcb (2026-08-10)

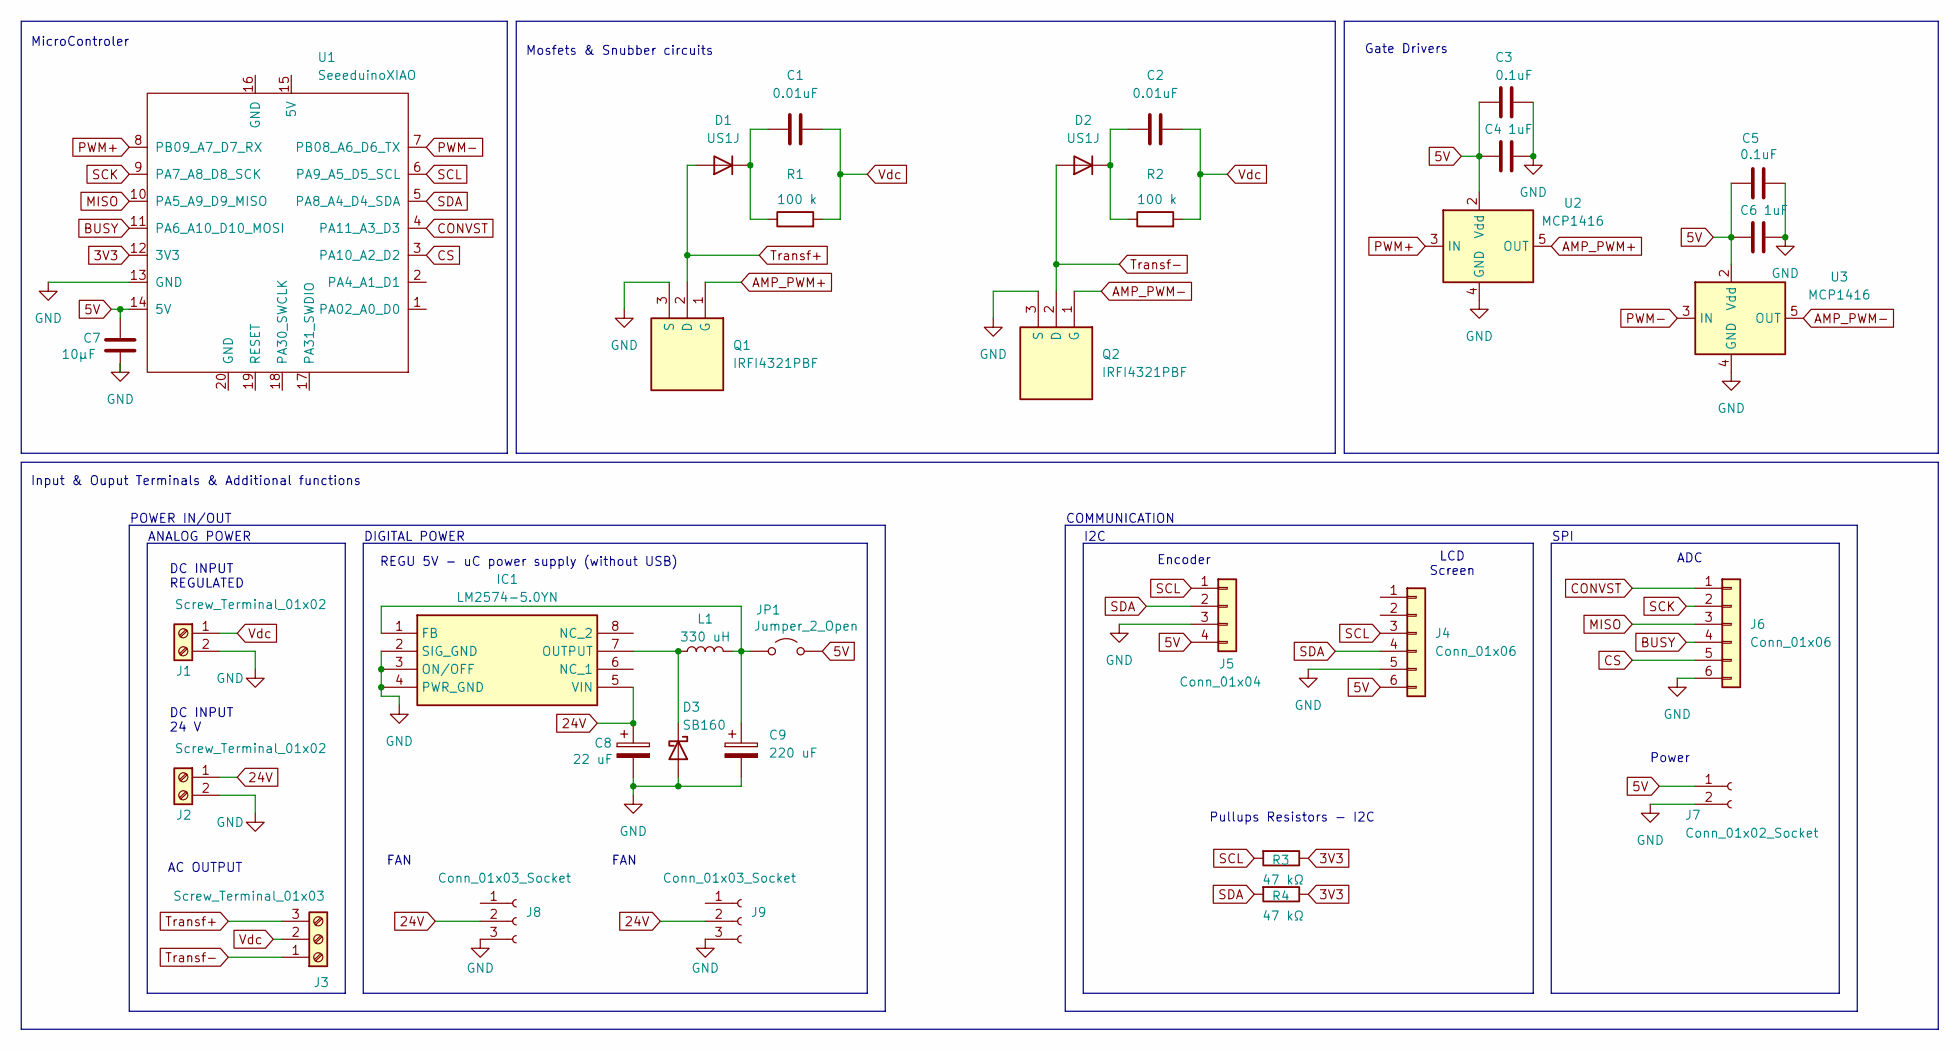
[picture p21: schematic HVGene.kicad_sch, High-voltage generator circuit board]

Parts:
C1, C2: 0.01uF; C_Rect_L7.0mm_W3.5mm_P5.00mm
C3, C5: 0.1uF; C_Rect_L7.0mm_W3.5mm_P5.00mm
C4, C6: 1uF; C_Rect_L7.0mm_W4.5mm_P5.00mm
C7: 10µF; C_Rect_L7.0mm_W4.5mm_P5.00mm
C8: 22 uF; CAPPRD200W52D500H1250
C9: 220 uF; CAPPRD500W60D1000H1350
D1, D2: US1J; D_DO-41_SOD81_P2.54mm_Vertical_AnodeUp
D3: SB160; DIOAD1405W86L465D235
IC1: LM2574-5.0YN; DIP762W57P254L952H343Q8N; Mouser Part Number 998-LM2574-5.0YN
J1, J2: Screw_Terminal_01x02; PhoenixContact_MSTBA_2,5_2-G-5,08_1x02_P5.08mm_Horizontal
J3: Screw_Terminal_01x03; PhoenixContact_MSTBA_2,5_3-G-5,08_1x03_P5.08mm_Horizontal
J4, J6: Conn_01x06; JST_XH_B6B-XH-A_1x06_P2.50mm_Vertical
J5: Conn_01x04; JST_XH_B4B-XH-A_1x04_P2.50mm_Vertical
J7: Conn_01x02_Socket; JST_XH_B2B-XH-A_1x02_P2.50mm_Vertical
J8, J9: Conn_01x03_Socket; JST_XH_B3B-XH-A_1x03_P2.50mm_Vertical
JP1: Jumper_2_Open; PinHeader_1x02_P2.54mm_Vertical
L1: 330 uH; WE-TIS_111190
Q1, Q2: IRFI4321PBF; TO254P483X1018X2095-3P; Mouser Part Number 942-IRFI4321PBF
R1, R2: 100 k; R_Axial_DIN0516_L15.5mm_D5.0mm_P5.08mm_Vertical
R3, R4: 47 kΩ; R_Axial_DIN0207_L6.3mm_D2.5mm_P2.54mm_Vertical
U1: SeeeduinoXIAO; SeeedStudio_XIAO_RP2040
U2, U3: MCP1416; SOT-23-5

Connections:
3V3: R3.1, R4.1, U1.12 (3V3); also elsewhere on the board
5V: C3.1, C4.1, C5.1, C6.1, C7.1, J4.6, J5.4, J7.1, JP1.2 (B), U1.14 (5V), U2.2 (Vdd), U3.2 (Vdd)
24V: C8.1, IC1.5 (VIN), J2.1, J8.2, J9.2
AMP_PWM+: Q1.1 (G), U2.5 (OUT)
AMP_PWM-: Q2.1 (G), U3.5 (OUT)
BUSY: J6.4, U1.11 (PA6_A10_D10_MOSI)
CONVST: J6.1, U1.4 (PA11_A3_D3)
CS: J6.5, U1.3 (PA10_A2_D2)
GND: C3.2, C4.2, C5.2, C6.2, C7.2, C8.2, C9.2, D3.2 (A), IC1.2 (SIG_GND), IC1.3 (ON/OFF), IC1.4 (PWR_GND), J1.2, J2.2, J4.5, J5.3, J6.6, J7.2, J8.3, J9.3, Q1.3 (S), Q2.3 (S), U1.13 (GND), U2.4 (GND), U3.4 (GND)
MISO: J6.3, U1.10 (PA5_A9_D9_MISO)
unnamed: C1.2, D1.1 (K), R1.1
unnamed: C2.2, D2.1 (K), R2.1
unnamed: D3.1 (K), IC1.7 (OUTPUT), L1.1
unnamed: C9.1, IC1.1 (FB), JP1.1 (A), L1.2
PWM+: U1.8 (PB09_A7_D7_RX), U2.3 (IN)
PWM-: U1.7 (PB08_A6_D6_TX), U3.3 (IN)
SCK: J6.2, U1.9 (PA7_A8_D8_SCK)
SCL: J4.3, J5.1, R3.2, U1.6 (PA9_A5_D5_SCL); also elsewhere on the board
SDA: J4.4, J5.2, R4.2, U1.5 (PA8_A4_D4_SDA)
Transf+: D1.2 (A), J3.3, Q1.2 (D)
Transf-: D2.2 (A), J3.1, Q2.2 (D)
Vdc: C1.1, C2.1, J1.1, J3.2, R1.2, R2.2

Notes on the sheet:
Pullups Resistors - I2C
DC INPUT REGULATED
FAN
REGU 5V - uC power supply (without USB)
Power
DC INPUT 24 V
POWER IN/OUT
ANALOG POWER
I2C
COMMUNICATION
MicroControler
SPI
Input & Ouput Terminals & Additional functions
Mosfets & Snubber circuits
AC OUTPUT
Gate Drivers
DIGITAL POWER
Encoder
LCD Screen
ADC

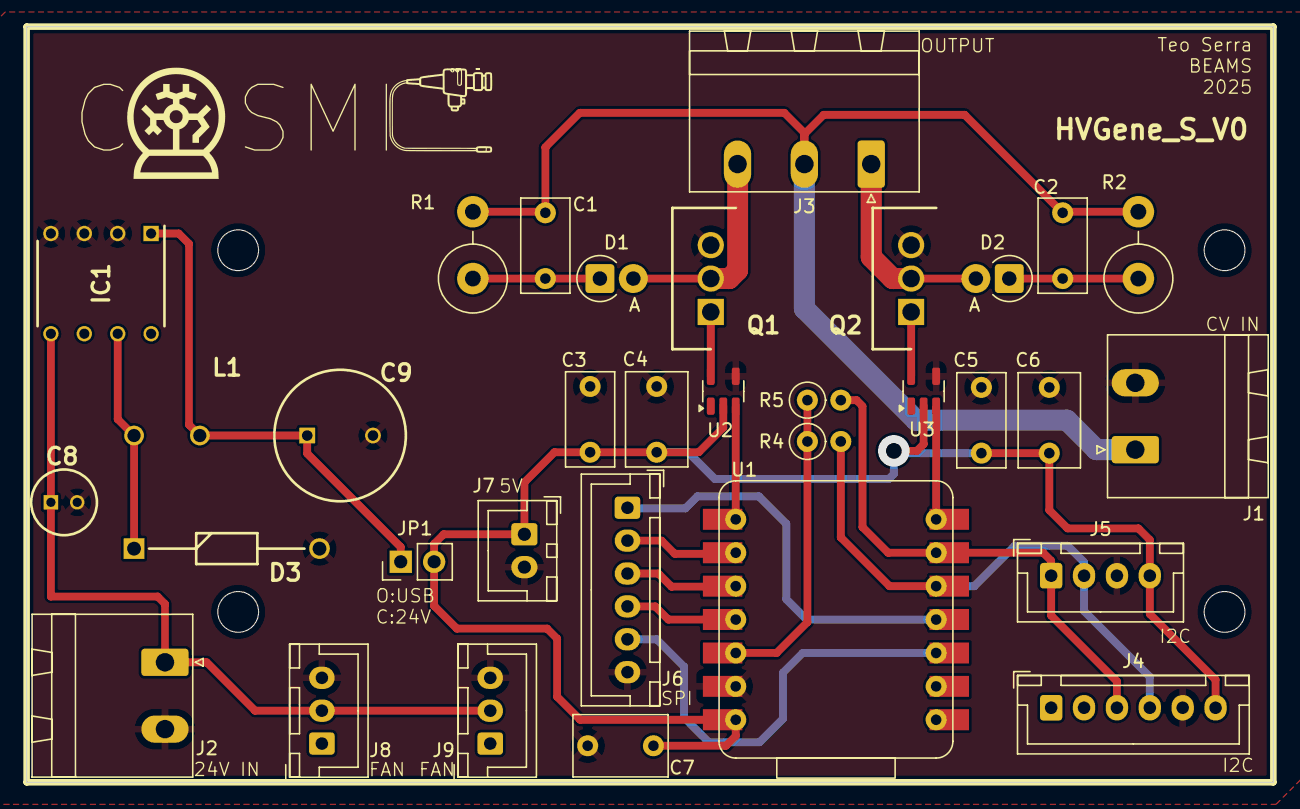
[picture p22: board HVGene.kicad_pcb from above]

Board: 2 copper layers, 94.8 x 57.5 mm, 33 parts (0 on the bottom side), 22 nets.

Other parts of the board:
R5: 47 kΩ; R_Axial_DIN0207_L6.3mm_D2.5mm_P2.54mm_Vertical

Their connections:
3V3: R5.1; also elsewhere on the board
SCL: R5.2; also elsewhere on the board

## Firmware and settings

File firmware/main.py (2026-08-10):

"""
High-Voltage Generator - Main entry point.
Refactored modular version.

This file initializes peripherals and starts the generator.
The application logic lives in lib/.
"""

import time

from machine import I2C, Pin
from rp2 import StateMachine

from lib.config import ENCODER_ADDR, I2C_FREQ, LCD_ADDR, PIN_SCL, PIN_SDA, PIN_SQUARE
from lib.generator import HTGenerator
from lib.pio_programs import gate_pulse_outputs


# ----------------------------
# INITIALIZATION
# ----------------------------
def safe_hw_recovery():
    """Put the RP2040 back into a safe hardware state (SMs OFF + GPIO LOW)."""
    try:
        StateMachine(0).active(0)
    except Exception:
        pass

    try:
        StateMachine(1).active(0)
    except Exception:
        pass

    # Drive both push-pull outputs LOW (GPIO0 and GPIO1)
    try:
        gate_pulse_outputs(PIN_SQUARE, False)
    except Exception:
        pass

    try:
        Pin(PIN_SQUARE, Pin.OUT).value(0)
        Pin(PIN_SQUARE + 1, Pin.OUT).value(0)
    except Exception:
        pass


def main():
    """Main entry point with automatic restart on error."""
    while True:
        try:
            # Preventive cleanup on each cycle to avoid stuck PIO/GPIO states.
            safe_hw_recovery()

            # Initialize the I2C bus
            i2c = I2C(1, scl=Pin(PIN_SCL), sda=Pin(PIN_SDA), freq=I2C_FREQ)

            # Create and run the generator
            generator = HTGenerator(i2c, LCD_ADDR, ENCODER_ADDR)
            try:
                generator._update_display()
            except Exception:
                pass
            generator.run()

        except Exception as e:
            # Ultimate safety net: force outputs LOW before retrying.
            safe_hw_recovery()

            print(f"[FATAL] main loop crash: {e}")
            time.sleep_ms(1000)


# ----------------------------
# PROGRAM START
# ----------------------------
if __name__ == "__main__":
    main()

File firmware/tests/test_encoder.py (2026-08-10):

"""
Quick test to verify I2C communication with the M5Stack U135 encoder.
Run in Thonny or via REPL to diagnose the I2C wiring.
"""

from machine import Pin, I2C
import time

# I2C configuration
SDA_PIN = 6
SCL_PIN = 7
I2C_FREQ = 50000

# I2C addresses
ENCODER_ADDR = 0x40
LCD_ADDR = 0x28

# M5Stack U135 registers
REG_ENCODER = 0x10
REG_BUTTON = 0x20
REG_RGB_LED = 0x30
BUTTON_ACTIVE_LOW = True

def scan_i2c_bus():
    """Scan the I2C bus to detect peripherals."""
    print("=== I2C bus scan ===")
    i2c = I2C(1, scl=Pin(SCL_PIN), sda=Pin(SDA_PIN), freq=I2C_FREQ)
    devices = i2c.scan()
    
    if not devices:
        print("[ERROR] No I2C peripherals detected")
        return None
    
    print(f"[OK] Detected peripherals: {len(devices)}")
    for addr in devices:
        print(f"  - Address: 0x{addr:02X}")
        if addr == ENCODER_ADDR:
            print("    - M5Stack U135 encoder")
        elif addr == LCD_ADDR:
            print("    - LCD controller")
    
    return i2c

def test_encoder(i2c):
    """Test encoder reading."""
    print("\n=== M5Stack U135 encoder test ===")
    
    if ENCODER_ADDR not in i2c.scan():
        print(f"[ERROR] Encoder not detected at address 0x{ENCODER_ADDR:02X}")
        return
    
    print("[OK] Encoder detected")
    print("Rotate the encoder to see values...")
    print("Press the button to test...")
    print("(Ctrl+C to stop)\n")
    
    last_value = 0
    
    # Automatic button polarity detection (active-low vs active-high)
    def _auto_detect_button(i2c, samples=10, delay_ms=10):
        ones = 0
        zeros = 0
        for _ in range(samples):
            try:
                b = int(i2c.readfrom_mem(ENCODER_ADDR, REG_BUTTON, 1)[0])
            except Exception:
                b = 0
            if b:
                ones += 1
            else:
                zeros += 1
            time.sleep_ms(delay_ms)
        # If most reads are 1, the released state is 1, which means active-low
        return ones >= zeros

    try:
        detected = _auto_detect_button(i2c)
    except Exception:
        detected = BUTTON_ACTIVE_LOW
    # Prefer automatic detection
    button_active_low = detected
    # Variables for debounce and reduced output
    last_btn_raw = None
    stable_count = 0
    STABLE_THRESHOLD = 3
    last_pressed_state = False

    try:
        while True:
            # Read encoder value
            try:
                data = i2c.readfrom_mem(ENCODER_ADDR, REG_ENCODER, 2)
                value = data[0] | (data[1] << 8)
                if value >= 32768:
                    value -= 65536
                
                if value != last_value:
                    increment = value - last_value
                    print(f"Encoder: {value:5d} (delta: {increment:+3d})")
                    last_value = value
            except OSError as e:
                print(f"Encoder read error: {e}")
            
            # Read the button (with debounce)
            try:
                btn_data = i2c.readfrom_mem(ENCODER_ADDR, REG_BUTTON, 1)
                raw = int(btn_data[0])
                # Debounce: count consecutive identical reads
                if last_btn_raw is None or raw != last_btn_raw:
                    last_btn_raw = raw
                    stable_count = 1
                else:
                    stable_count += 1

                # When the state is stable for STABLE_THRESHOLD reads, display it
                if stable_count == STABLE_THRESHOLD:
                    print(f"Raw button value (stable): {raw}")
                    if button_active_low:
                        pressed = (raw == 0)
                    else:
                        pressed = (raw != 0)

                    if pressed and not last_pressed_state:
                        print("[BUTTON] PRESSED")
                    elif not pressed and last_pressed_state:
                        print("[BUTTON] RELEASED")
                    last_pressed_state = pressed
            except OSError as e:
                print(f"Button read error: {e}")
            
            time.sleep_ms(50)
    
    except KeyboardInterrupt:
        print("\n\n[OK] Test complete")

def test_rgb_led(i2c):
    """Test the encoder RGB LEDs."""
    print("\n=== RGB LED test ===")
    
    if ENCODER_ADDR not in i2c.scan():
        print("[ERROR] Encoder not detected")
        return
    
    colors = [
        ("Red", 1, 100, 0, 0),
        ("Green", 1, 0, 100, 0),
        ("Blue", 1, 0, 0, 100),
        ("Yellow", 1, 100, 100, 0),
        ("Cyan", 1, 0, 100, 100),
        ("Magenta", 1, 100, 0, 100),
        ("White", 1, 100, 100, 100),
        ("Off", 1, 0, 0, 0),
    ]
    
    for name, led, r, g, b in colors:
        print(f"LED {led}: {name} (R:{r}, G:{g}, B:{b})")
        try:
            data = bytes([led, r, g, b])
            i2c.writeto_mem(ENCODER_ADDR, REG_RGB_LED, data)
            time.sleep_ms(500)
        except OSError as e:
            print(f"[ERROR] {e}")
    
    print("[OK] LED test complete")

def main():
    """Main test program."""
    print("\n" + "="*50)
    print("M5Stack U135 encoder I2C test")
    print("="*50 + "\n")
    
    # Scan the I2C bus.
    i2c = scan_i2c_bus()
    
    if i2c is None:
        print("\n[ERROR] Check the I2C connections:")
        print(f"  - SDA: GPIO {SDA_PIN}")
        print(f"  - SCL: GPIO {SCL_PIN}")
        print(f"  - VCC: 5V")
        print(f"  - GND: GND")
        return
    
    # Test menu
    print("\n=== Test menu ===")
    print("1. Scan the I2C bus")
    print("2. Test the encoder (rotation + button)")
    print("3. Test the RGB LEDs")
    print("4. Run everything")
    
    # For now, run the encoder test directly.
    # In a REPL, you can call the functions individually.
    test_encoder(i2c)

if __name__ == "__main__":
    main()

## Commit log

2026-08-10 Initial public release: hardware, firmware, and documentation for HVGene
    Accompanies the HardwareX article "Open-Source High Voltage Power Supply
    for Cold Atmospheric Plasma Production".
    - hardware/: KiCAD PCB, Fusion360 mechanical design, laser-cutting SVGs, BOM (CERN-OHL-P-2.0)
    - firmware/: RP2040 MicroPython control firmware (MIT)
    - docs/: article figures, build/device/plasma photos, diagrams (CC BY-SA 4.0)
    [7447471331.stp, 860020672011.SchLib, 860020672011.stp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]
2026-08-12 Update BOM, remove obsolete bolt CAD, add missing files
    - Replace BOM.xlsx with rebuilt single-table version (all items sourced,
    WAGO 221-415 5-way connector priced, total 431.67 EUR)
    - Remove CAD (f3d/step) for 4 bolt variants no longer used in the design
    (BOLT_BHSCS_M3_6mm, BOLT_SHCS_M1.6_8mm, BOLT_SHCS_M2_12mm, BOLT_SHCS_M4_16mm)
    - Add missing device photo to docs/Figures
    - Add firmware/tests/lib/ (pio_programs.py + __init__.py), required by
    test_duty_pushpull.py at runtime via sys.path.insert(0, "/tests")
    - Add sub-assembly CAD files (SA_HV_MODULE, SA_LV_MODULE,
    SA_MakerBeam_CORNER, SA_MakerBeam_HINGE)
    [BOLT_BHSCS_M3_6mm.f3d, BOLT_BHSCS_M3_6mm.step, BOLT_SHCS_M1.6_8mm.f3d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]
2026-10-15 Add validation dataset and final article figures
    - data/: validation dataset behind the article's validation section
    - docs/Figures/Article_Figures: article figures (Fig01-Fig29) and
    Supplementary Material figures (FigS1-FigS6)
    - docs/Figures/Diagrams: draw.io/TikZ sources of the diagrams
    - hardware/KiCAD/Article_Figure3_version: schematic as drawn in Figure 3
    - README: design files mapped to the article's Design files summary
2026-10-27 Update BOM and clarify THD units in validation dataset
    - hardware/BOM.xlsx: version of 2026-10-15 (total EUR 438.30), with the four
    MakerBeam kit links corrected.
    - data/: the THD column holds a fraction (0.11 = 11 %), not a percentage;
    header renamed to "THD (fraction)" and documented in data/README.md.
